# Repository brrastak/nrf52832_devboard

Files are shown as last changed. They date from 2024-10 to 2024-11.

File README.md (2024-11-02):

# nRF52832 development board

The project main intension is the first experiment in designing bluetooth hardware. Design is **not tested!**

The TI antenna SWRA117D is used (AN 043).

USB connector and voltage regulator circuitry are optional and only provide power.

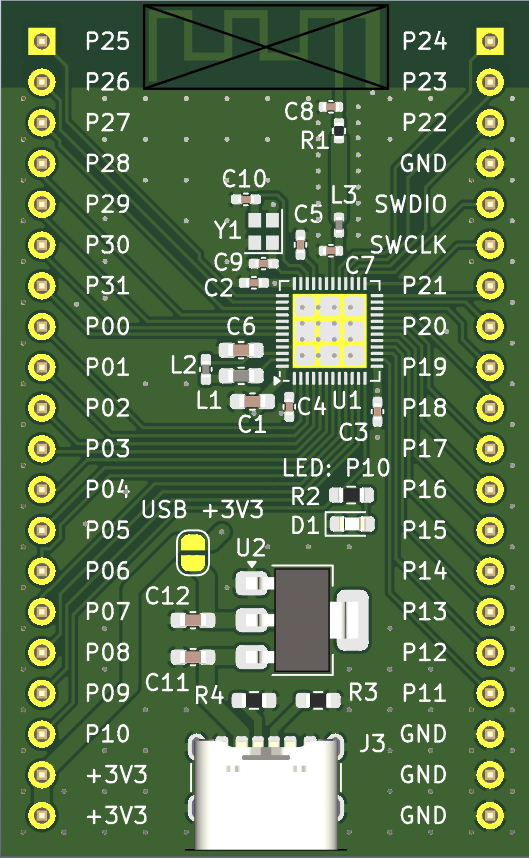
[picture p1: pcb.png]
PCB picture

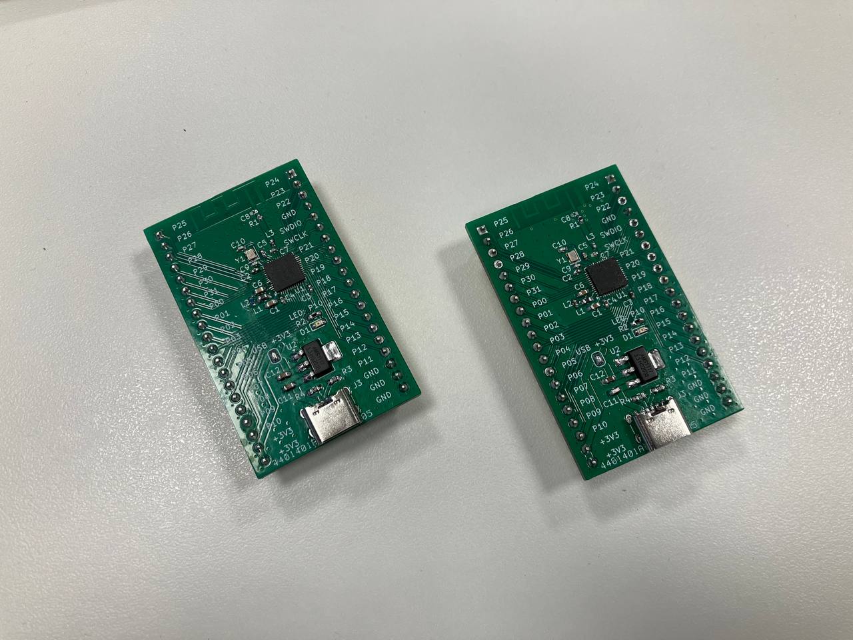
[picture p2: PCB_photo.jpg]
PCB photo


## Known issues

It turns out that using P10 as an LED pin is not the best idea, as it is one of the NFC pins. To use it as a GPIO, you first need to disable the NFC pin protection. Using Rust and the nRF52832 PAC, this is done with the following code (the dedicated NVRAM register value should be set once and the new configuration is taken into account after MCU reset):

```rust
p.NVMC.config.write(|w| w.wen().wen());
p.UICR.nfcpins.write(|w| w.protect().disabled());
p.NVMC.config.reset();
```

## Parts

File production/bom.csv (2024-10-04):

Id | Designator | Footprint | Quantity | Designation | Supplier and ref
1 | J3 | USB_C_Receptacle_GCT_USB4125-xx-x_6P_TopMnt_Horizontal | 1 | USB_C_Receptacle_PowerOnly_6P
2 | D1 | LED_0603_1608Metric_Pad1.05x0.95mm_HandSolder | 1 | LED
3 | R3,R4 | R_0603_1608Metric_Pad0.98x0.95mm_HandSolder | 2 | 5.1k
4 | C7 | C_0402_1005Metric | 1 | 0.8p NP0 5%
5 | Y1 | Crystal_SMD_2016-4Pin_2.0x1.6mm | 1 | 32MHz 8pF 40ppm
6 | C1 | C_0603_1608Metric_Pad1.08x0.95mm_HandSolder | 1 | 4.7u
7 | C6 | C_0603_1608Metric_Pad1.08x0.95mm_HandSolder | 1 | 1.0u
8 | C5 | C_0402_1005Metric_Pad0.74x0.62mm_HandSolder | 1 | 100p NP0 5%
9 | C4,C2,C3 | C_0402_1005Metric_Pad0.74x0.62mm_HandSolder | 3 | 0.1u
10 | AE1 | Texas_SWRA117D_2.4GHz_Left | 1 | SWRA117D_2.4GHz
11 | L1 | L_0603_1608Metric_Pad1.05x0.95mm_HandSolder | 1 | 10uH 50mA
12 | C8 | C_0402_1005Metric | 1 | NA
13 | R1 | R_0402_1005Metric | 1 | 0
14 | U1 | QFN-48-1EP_6x6mm_P0.4mm_EP4.6x4.6mm | 1 | nRF52832-QFAA
15 | C11,C12 | C_0603_1608Metric_Pad1.08x0.95mm_HandSolder | 2 | 10u
16 | L3 | L_0402_1005Metric | 1 | 3.9nH RF 5%
17 | R2 | R_0603_1608Metric_Pad0.98x0.95mm_HandSolder | 1 | 10k
18 | L2 | L_0402_1005Metric_Pad0.77x0.64mm_HandSolder | 1 | 15nH RF 10%
19 | C9 | C_0402_1005Metric_Pad0.74x0.62mm_HandSolder | 1 | 12p
20 | U2 | SOT-223-3_TabPin2 | 1 | AMS1117-3.3
21 | C10 | C_0402_1005Metric_Pad0.74x0.62mm_HandSolder | 1 | 12p 2%
22 | G1 | stamp | 1 | stamp
23 | J2,J1 | PinHeader_1x20_P2.54mm_Vertical | 2 | Conn_01x20_Pin

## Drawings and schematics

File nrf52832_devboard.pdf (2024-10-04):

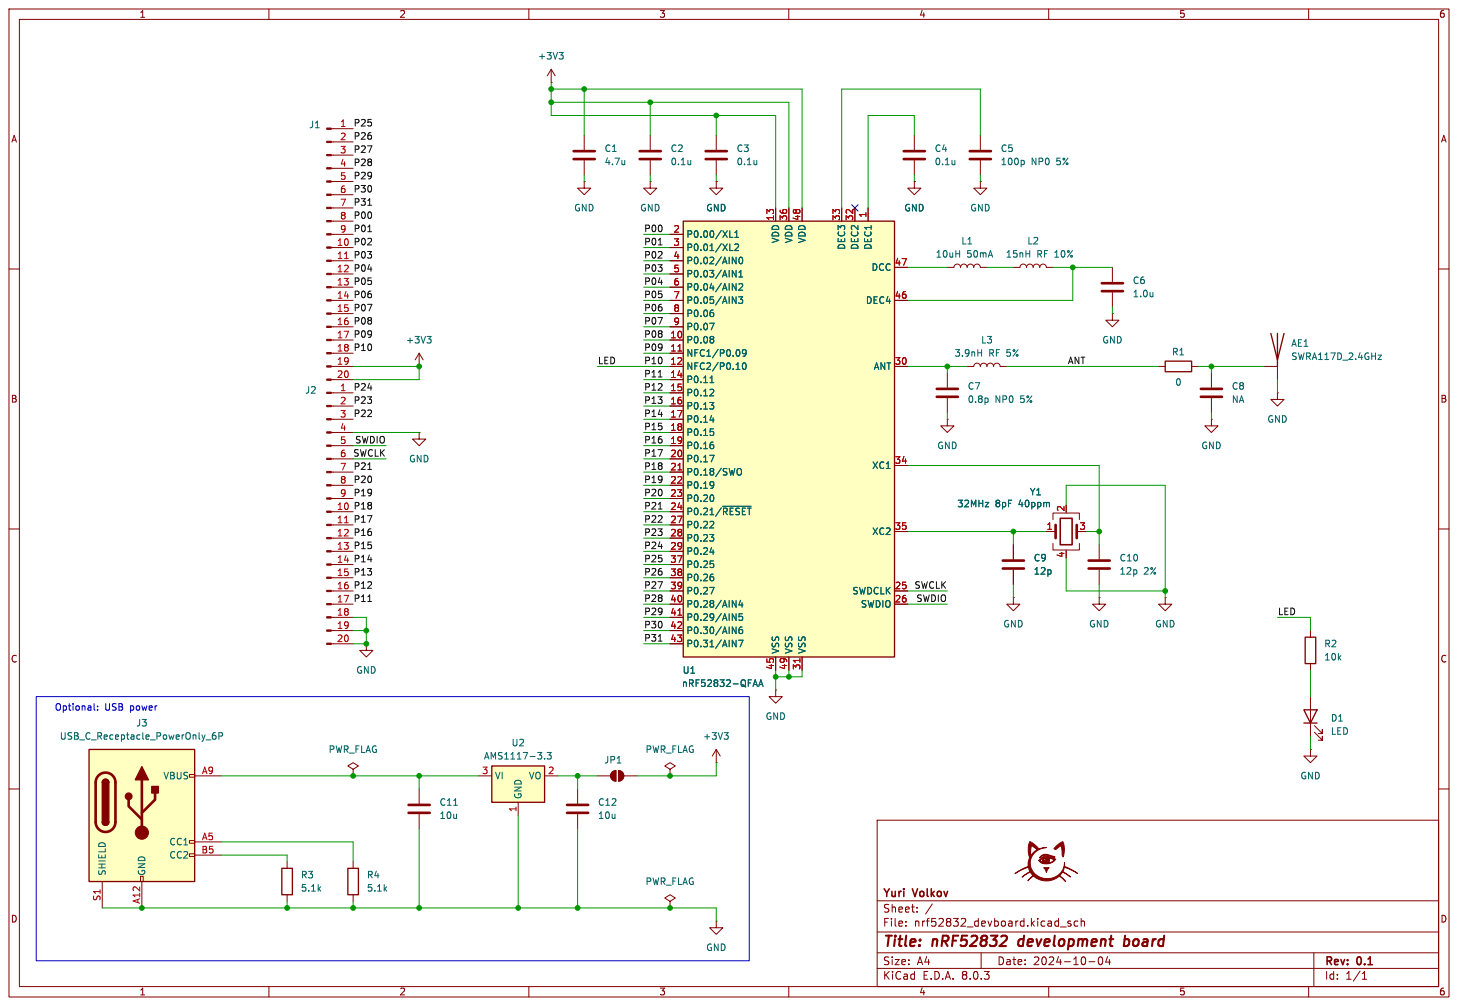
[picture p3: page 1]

File: nrf52832_devboard.kicad_sch Sheet: / Yuri Volkov

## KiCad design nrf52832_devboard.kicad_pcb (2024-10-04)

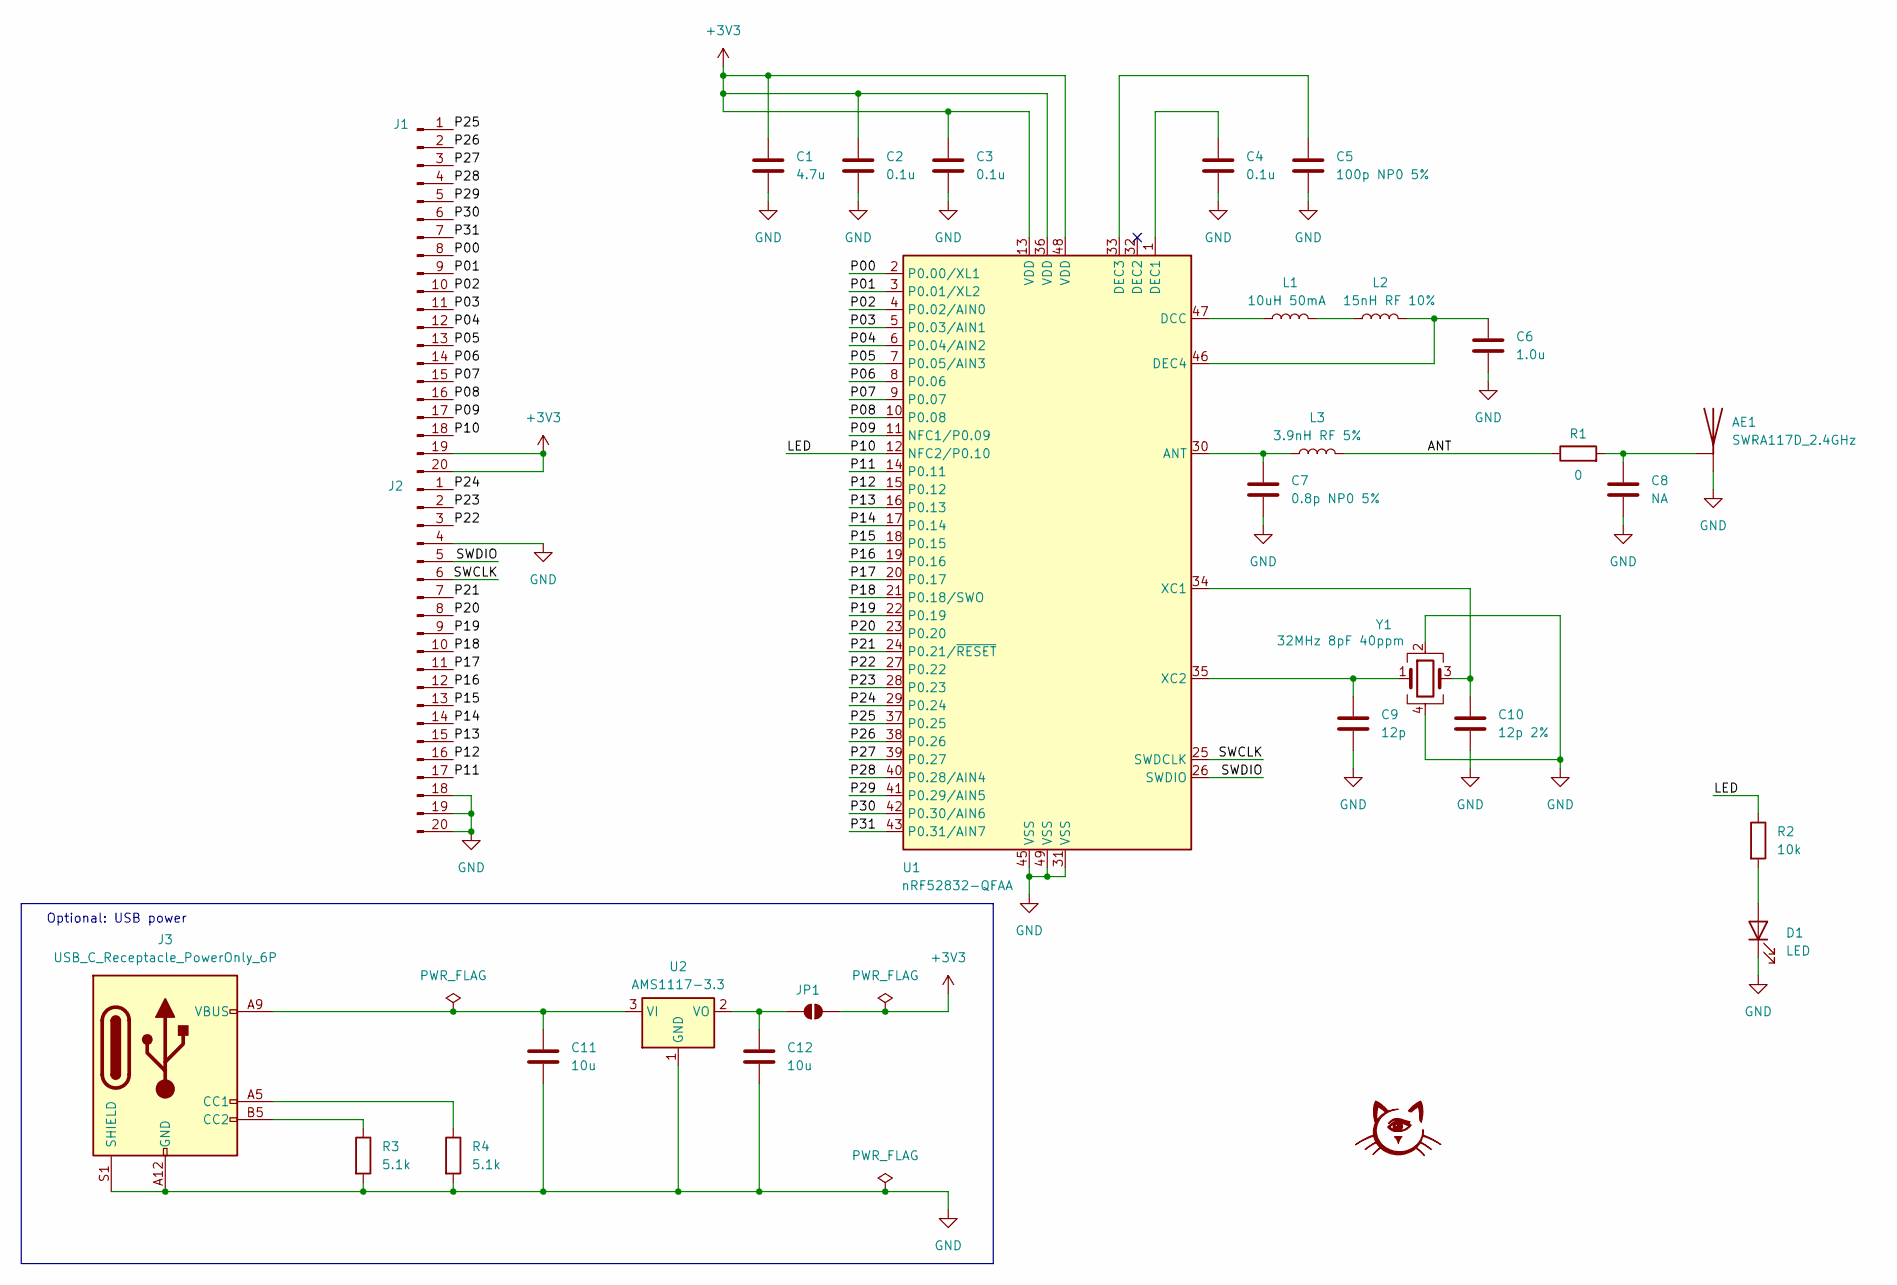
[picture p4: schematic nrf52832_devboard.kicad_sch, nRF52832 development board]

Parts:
AE1: SWRA117D_2.4GHz; Texas_SWRA117D_2.4GHz_Left
C1: 4.7u; C_0603_1608Metric_Pad1.08x0.95mm_HandSolder
C2, C3, C4: 0.1u; C_0402_1005Metric_Pad0.74x0.62mm_HandSolder
C5: 100p NP0 5%; C_0402_1005Metric_Pad0.74x0.62mm_HandSolder
C6: 1.0u; C_0603_1608Metric_Pad1.08x0.95mm_HandSolder
C7: 0.8p NP0 5%; C_0402_1005Metric
C8: NA; C_0402_1005Metric
C9: 12p; C_0402_1005Metric_Pad0.74x0.62mm_HandSolder
C10: 12p 2%; C_0402_1005Metric_Pad0.74x0.62mm_HandSolder
C11, C12: 10u; C_0603_1608Metric_Pad1.08x0.95mm_HandSolder
D1: LED; LED_0603_1608Metric_Pad1.05x0.95mm_HandSolder
G1: stamp
J1, J2: Conn_01x20_Pin; PinHeader_1x20_P2.54mm_Vertical
J3: USB_C_Receptacle_PowerOnly_6P; USB_C_Receptacle_GCT_USB4125-xx-x_6P_TopMnt_Horizontal
JP1: SolderJumper_2_Open; SolderJumper-2_P1.3mm_Open_RoundedPad1.0x1.5mm
L1: 10uH 50mA; L_0603_1608Metric_Pad1.05x0.95mm_HandSolder
L2: 15nH RF 10%; L_0402_1005Metric_Pad0.77x0.64mm_HandSolder
L3: 3.9nH RF 5%; L_0402_1005Metric
R1: 0; R_0402_1005Metric
R2: 10k; R_0603_1608Metric_Pad0.98x0.95mm_HandSolder
R3, R4: 5.1k; R_0603_1608Metric_Pad0.98x0.95mm_HandSolder
U1: nRF52832-QFAA; QFN-48-1EP_6x6mm_P0.4mm_EP4.6x4.6mm
U2: AMS1117-3.3; SOT-223-3_TabPin2
Y1: 32MHz 8pF 40ppm; Crystal_SMD_2016-4Pin_2.0x1.6mm

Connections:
+3V3: C1.1, C2.1, C3.1, J1.19, J1.20, JP1.2 (B), U1.13 (VDD), U1.36 (VDD), U1.48 (VDD)
/ANT: L3.2, R1.1
/LED: J1.18, R2.1, U1.12 (NFC2/P0.10)
/P00: J1.8, U1.2 (P0.00/XL1)
/P01: J1.9, U1.3 (P0.01/XL2)
/P02: J1.10, U1.4 (P0.02/AIN0)
/P03: J1.11, U1.5 (P0.03/AIN1)
/P04: J1.12, U1.6 (P0.04/AIN2)
/P05: J1.13, U1.7 (P0.05/AIN3)
/P06: J1.14, U1.8 (P0.06)
/P07: J1.15, U1.9 (P0.07)
/P08: J1.16, U1.10 (P0.08)
/P09: J1.17, U1.11 (NFC1/P0.09)
/P11: J2.17, U1.14 (P0.11)
/P12: J2.16, U1.15 (P0.12)
/P13: J2.15, U1.16 (P0.13)
/P14: J2.14, U1.17 (P0.14)
/P15: J2.13, U1.18 (P0.15)
/P16: J2.12, U1.19 (P0.16)
/P17: J2.11, U1.20 (P0.17)
/P18: J2.10, U1.21 (P0.18/SWO)
/P19: J2.9, U1.22 (P0.19)
/P20: J2.8, U1.23 (P0.20)
/P21: J2.7, U1.24 (P0.21/~RESET)
/P22: J2.3, U1.27 (P0.22)
/P23: J2.2, U1.28 (P0.23)
/P24: J2.1, U1.29 (P0.24)
/P25: J1.1, U1.37 (P0.25)
/P26: J1.2, U1.38 (P0.26)
/P27: J1.3, U1.39 (P0.27)
/P28: J1.4, U1.40 (P0.28/AIN4)
/P29: J1.5, U1.41 (P0.29/AIN5)
/P30: J1.6, U1.42 (P0.30/AIN6)
/P31: J1.7, U1.43 (P0.31/AIN7)
/SWCLK: J2.6, U1.25 (SWDCLK)
/SWDIO: J2.5, U1.26 (SWDIO)
GND: AE1.2 (A), C1.2, C2.2, C3.2, C4.2, C5.2, C6.2, C7.2, C8.2, C9.2, C10.2, C11.2, C12.2, D1.1 (K), J2.4, J2.18, J2.19, J2.20, J3.A12 (GND), J3.B12 (GND), J3.S1 (SHIELD), R3.2, R4.2, U1.31 (VSS), U1.45 (VSS), U1.49 (VSS), U2.1 (GND), Y1.2, Y1.4
unnamed: AE1.1 (A), C8.1, R1.2
unnamed: D1.2 (A), R2.2
unnamed: J3.A5 (CC1), R4.1
unnamed: J3.B5 (CC2), R3.1
unnamed: C12.1, JP1.1 (A), U2.2 (VO)
unnamed: L1.2, L2.1
unnamed: C7.1, L3.1, U1.30 (ANT)
unnamed: L1.1, U1.47 (DCC)
unnamed: C4.1, U1.1 (DEC1)
unnamed: C5.1, U1.33 (DEC3)
unnamed: C6.1, L2.2, U1.46 (DEC4)
unnamed: C10.1, U1.34 (XC1), Y1.3
unnamed: C9.1, U1.35 (XC2), Y1.1
unnamed: C11.1, J3.A9 (VBUS), J3.B9 (VBUS), U2.3 (VI)

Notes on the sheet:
Optional: USB power

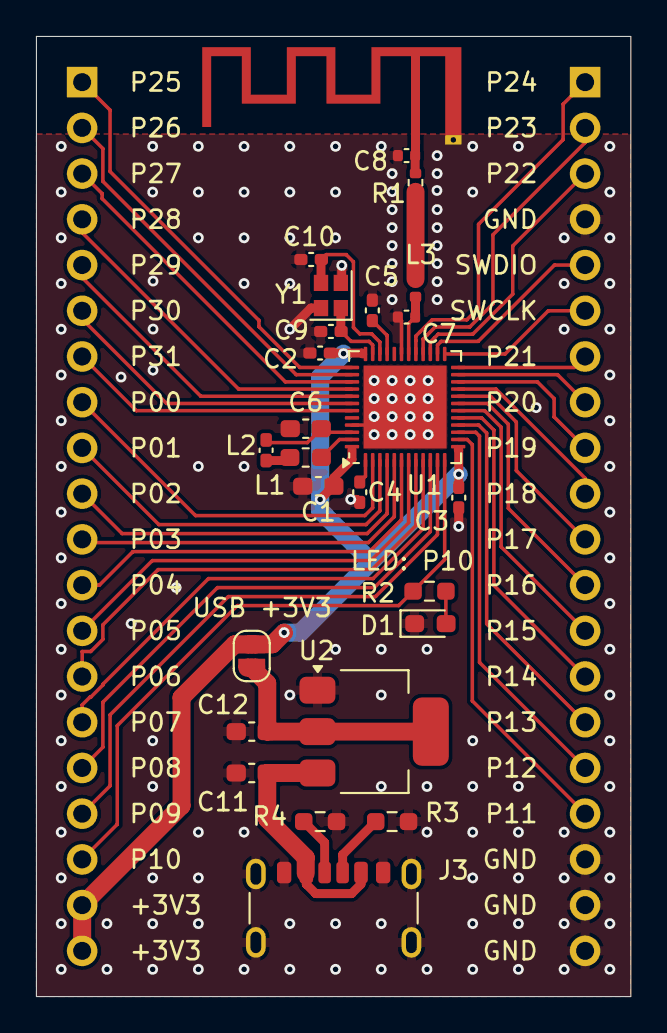
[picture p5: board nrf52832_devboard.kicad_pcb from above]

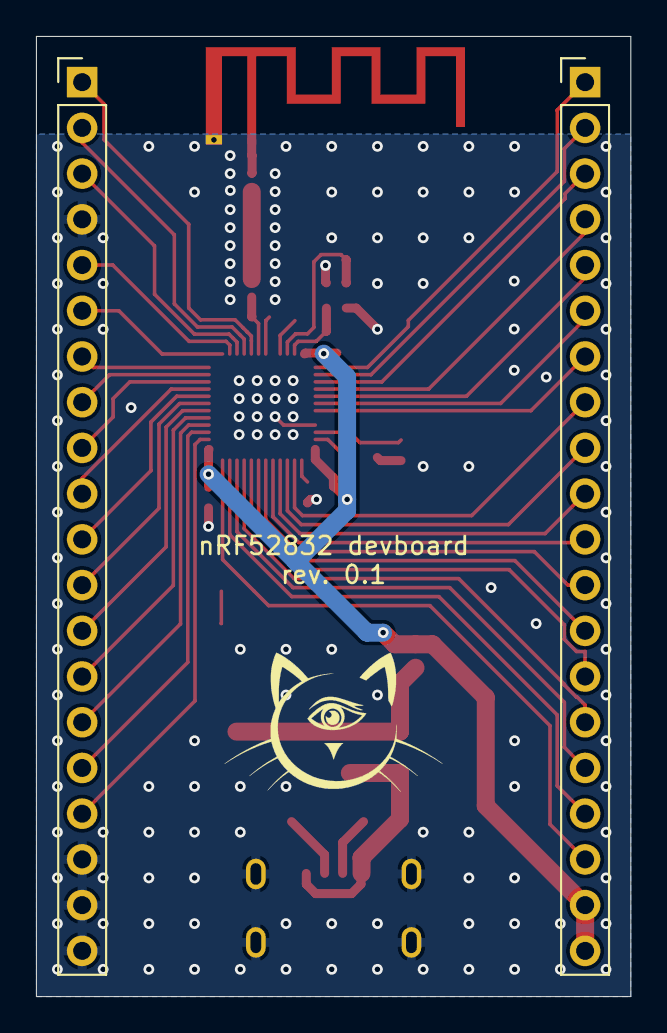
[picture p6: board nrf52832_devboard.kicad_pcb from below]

Board: 2 copper layers, 33.0 x 53.3 mm, 29 parts (3 on the bottom side), 51 nets.

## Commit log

2024-10-04 Initial commit rev. 0.1
    [bom.csv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]
2024-10-04 Update BOM
    [bom.csv, nrf52832_devboard.kicad_pcb, nrf52832_devboard.kicad_sch]
